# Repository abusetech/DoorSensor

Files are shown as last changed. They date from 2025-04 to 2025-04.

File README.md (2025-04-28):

# DoorSensor

This is a wireless sensor that uses an accelerometer and an NRF24l01+ wireless transceiver to monitor the state of a door thumbturn (The small knob that moves the deadbolt). The sensor physically attaches to the deadbolt and uses the accelerometer to deterimine its orientation and therefore the state of the deadbolt. This allows the device to be attached to the door without modifying the entry or causing damage. This is important in scenarios such as apartment rentals as lease agreements typically do not allow tenants to modify or replace the door lock.

This sensor is battery operated and designed to have very low power comsumption in order to allow the batteries to last a long time.

### Project contents

* Circuit schematic (board design coming soon!)
* Firmware sources, including some novel abstractions for the accelerometer and radio
* Arduino code to receive data from the remote sensor (coming soon)
* Testing tools for various parts of the project

### Firmware features

* A tiny, highly optimized software TWI (I2C compatible) implementation
* Firmware code optimized for ultra low power consumption battery powered operation

### Parts

* ATTINY44/84
* ADXL345
* NRF24L01(+) module
* 2x AAA battery holder

You will also need an Arduino board and a second NRF24L01+ to build the receiver.

### Project Plan

The Arduino will run firmware that allows it to connect to HomeAssistant. It acts as a bridge between the HomeAssistant and the wireless sensor.

### Building

Make a build directory:

`$ mkdir build`

Run `make`

`$ make all`

### Debugging

This project can be run in [simavr](https://github.com/buserror/simavr). To do so, build the binaries and then execute the ELF inside simavr:

`$ simavr -g build/attiny44.elf`

Then connect to simavr using gdb:

`avr-gdb -ex "symbol-file build/attiny44.elf" -ex "target remote localhost:1234"`

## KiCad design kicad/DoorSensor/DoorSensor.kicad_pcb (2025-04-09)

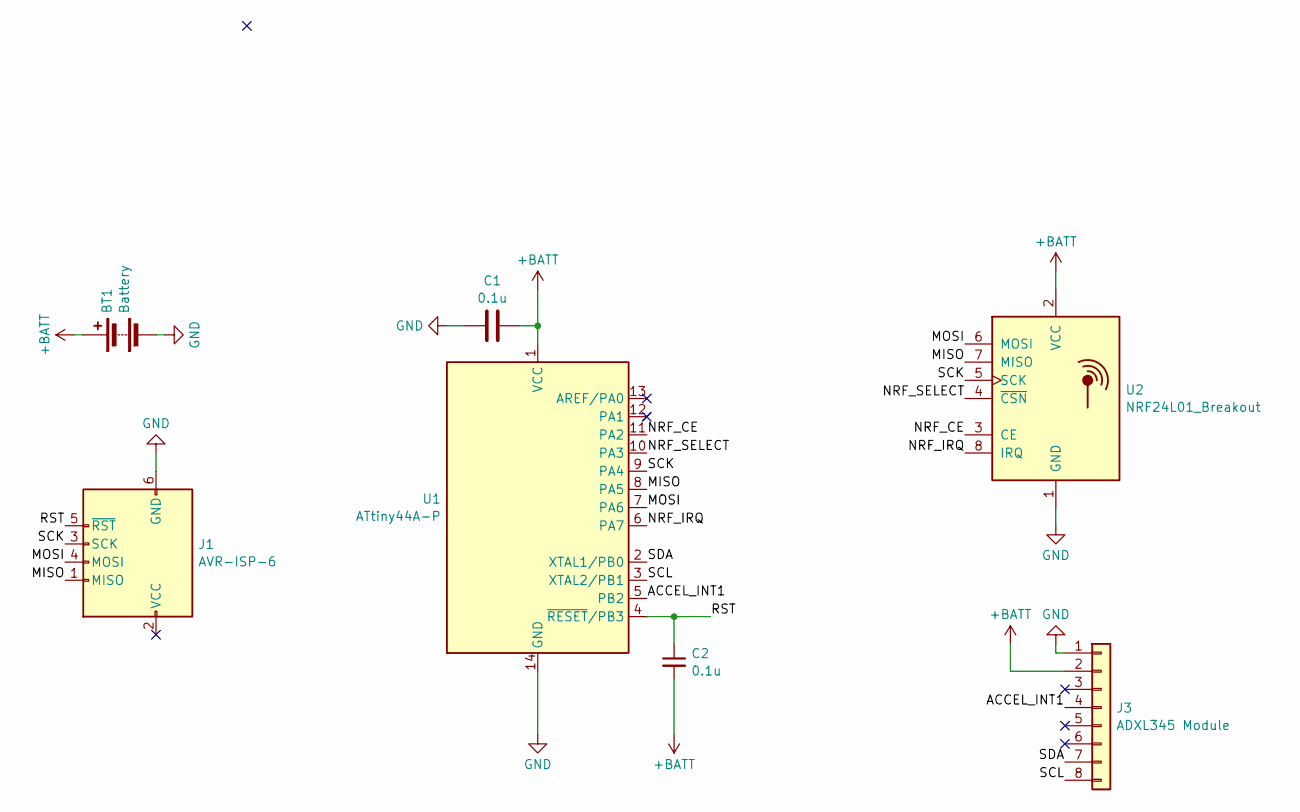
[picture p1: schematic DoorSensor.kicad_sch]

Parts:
BT1: Battery; TerminalBlock_4Ucon_1x02_P3.50mm_Horizontal
C1, C2: 0.1u; C_Disc_D4.3mm_W1.9mm_P5.00mm
J1: AVR-ISP-6; IDC-Header_2x03_P2.54mm_Vertical
J3: ADXL345 Module; PinHeader_1x08_P2.54mm_Vertical
U1: ATtiny44A-P; DIP-14_W7.62mm
U2: NRF24L01_Breakout; nRF24L01_Breakout

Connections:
+BATT: BT1.1 (+), C1.2, C2.2, J3.2, U1.1 (VCC), U2.2 (VCC)
/ACCEL_INT1: J3.4, U1.5 (PB2)
/MISO: J1.1 (MISO), U1.8 (PA5), U2.7 (MISO)
/MOSI: J1.4 (MOSI), U1.7 (PA6), U2.6 (MOSI)
/NRF_CE: U1.11 (PA2), U2.3 (CE)
/NRF_IRQ: U1.6 (PA7), U2.8 (IRQ)
/NRF_SELECT: U1.10 (PA3), U2.4 (~CSN)
/RST: C2.1, J1.5 (~RST), U1.4 (~RESET/PB3)
/SCK: J1.3 (SCK), U1.9 (PA4), U2.5 (SCK)
/SCL: J3.8, U1.3 (XTAL2/PB1)
/SDA: J3.7, U1.2 (XTAL1/PB0)
GND: BT1.2 (-), C1.1, J1.6 (GND), J3.1, U1.14 (GND), U2.1 (GND)

Board: 2 copper layers, 7 parts (1 on the bottom side), 12 nets, no tracks yet.

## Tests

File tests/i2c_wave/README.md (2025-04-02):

## I2C Wave

This is a tool for verification of the software I2C code. It utilizes a modified common.h header to inject some code into the software i2c library (softi2c.h). It is compiled using the system (as in the native one running on the development machine) C++ compiler. The customized header defines functions and variables to mock or emulate the functionality of the microcontroller. The test produces a CSV file that is read into a MATLAP / Octave sctipt that is then executed with Octave to produce a graph of the pin states.

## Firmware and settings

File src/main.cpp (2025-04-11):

#include <stdint.h>
#include <avr/io.h>
#include <avr/interrupt.h>
#include <avr/sleep.h>
#include <avr/wdt.h>
//Common.h defines F_CPU, so it must be included before delay.h
#include "common.h"
#include <util/delay.h>
#include "spi.h"
#include "softi2c.h"
#include "nrf24.h"
#include "adxl345.h"
#include "battery.h"

#define NRF_SPI_CS_PORT PORTA
#define NRF_SPI_CE_PORT PORTA
#define NRF_SPI_CS PA1
#define NRF_SPI_CE PA3
//Resolution of STATUS_TX_PERIOD is the same as the WDT timeout setting.
#define STATUS_TX_PERIOD 30

//f = 2400 + RF_CH MHz
#define RF_CHAN (25)
const uint8_t DEST_ADDRESS[5] = {0x7E, 0x7E, 0x7E, 0x7E, 0x7E};

int main (void);
void txStatus(ADXL345&);

volatile uint16_t wdt_timer = 0;
SPI nrf_spi(&NRF_SPI_CS_PORT, NRF_SPI_CS);
SoftI2C i2c;
NRF24 nrf(nrf_spi, &NRF_SPI_CE_PORT, NRF_SPI_CE);
ADXL345 accel(i2c);

//On AVR platforms, this packet will be little-endian 2's complement format
typedef struct __attribute__((packed)) status_packet {
    uint8_t sensorClass;
    uint8_t sensorID;
    uint8_t locked;
    uint16_t battery_mv;
} status_packet_t;

int main (void){
    nrf_spi.init();
    i2c.init();
    //Disable WDT, it may still be enabled after reset
    wdt_disable();
    //Wait ~100ms for periphrials to settle
    _delay_ms(100);
    //Bypass the FIFO, old values overwritten as they come in. 
    accel.fifoCtl(ADXL_FIFO_MODE_BYPASS, 0, 0);
    //Select the measurement rate. 0b0011 = 0.78Hz, 23uA consumption.
    //TODO: Power consumption could be further reduced to ~0.1uA by using standby mode (clearing the measure bit).
    accel.bwRate(0, 0b0011);
    //Enable measurement mode.
    accel.powerCtl(ADXL_POWER_MEASURE, 0);
    //Configure the NRF24L01+ module
    nrf.setDestAddress(DEST_ADDRESS, sizeof(DEST_ADDRESS));
    nrf.setChannel(RF_CHAN);
    //Enable interrupts
    sei();
    //Configure WDT. We need this to bring the chip out of standby.
    wdt_enable(WDTO_8S);
    //WDT triggers an interrupt.
    WDTCSR |= (1 << WDIE);
    //Set the sleep mode
    set_sleep_mode(SLEEP_MODE_STANDBY);
    
    
    while(true){
        //Sleep. Zzzzz.
        sleep_enable();
        sleep_cpu();
        //Clear SE bit
        sleep_disable();
        if (wdt_timer >= STATUS_TX_PERIOD){
            wdt_timer = 0;
            BatteryStatus::init();
            nrf_spi.init(); //USI needs to be re initialized after waking from sleep
            txStatus(accel);
            BatteryStatus::shutdown();
        }
    }
}

void txStatus(ADXL345& accel){
    status_packet_t pkt;
    pkt.sensorClass = 15;
    pkt.sensorID = 103;
    //Read accelerometer status
    adxl_data_t accelData = accel.readFifo();
    //in +/- 2g mode, the axis scaling factor is 4mg / LSB.
    //therefore, we expect a read of ~250 for any axis pointed straight up.
    //if we take any angle > 30 degrees from vertical to be 'open'
    //then 250 * sqrt(3)/2 = 250 * 0.866 = 216.5
    pkt.locked = 1;
    if (accelData.datay < 216){
        pkt.locked = 0;
    }
    pkt.battery_mv = BatteryStatus::measure_mv();
    //transmit
    nrf.transmit(&pkt, sizeof(pkt));
}

ISR(WDT_vect){
    //Clear SE bit
    sleep_disable();
    wdt_timer += 8;
    //Next WDT triggers an interrupt.
    WDTCSR |= (1 << WDIE);
}

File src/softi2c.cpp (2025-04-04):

#include "softi2c.h"

/*
*
* Pins and port must be defined before this file is included.
* #define I2C_PORT PORTB
* #define I2C_PIN PINB
* #define I2C_DDR DDRB
* #define I2C_SDA PB0
* #define I2C_SCL PB1
* #define I2C_CLOCK_PERIOD 1000
*
*/

//The following one liners *SHOULD* compile to sbi or cbi instructions.
//No need for inline assembly here.

static inline void _I2C_SDA_LOW(){
    I2C_DDR |= (1 << I2C_SDA);
}

static inline void _I2C_SDA_HIGH(){
    I2C_DDR &= ~(1 << I2C_SDA);
};

static inline void _I2C_SCL_LOW(){
    I2C_DDR |= (1 << I2C_SCL);
}

static inline void _I2C_SCL_HIGH(){
    I2C_DDR &= ~(1 << I2C_SCL);
};

//returns 1 or 0 depending on the state of the SDA pin
static inline uint8_t _I2C_READ_SDA(){
    return (I2C_PIN & (1 << I2C_SDA)) >> I2C_SDA;
}

//PUMP_BIT puts a bit onto the bus, starting 1/4 cycle before the rising edge of the clock
//and waiting 1/4 cycle of space (clock low) time.
static void _I2C_PUMP_BIT(uint8_t b){
    _I2C_SCL_LOW();
    if (b>0){
        _I2C_SDA_HIGH();
    }else{
        _I2C_SDA_LOW();
    }
    _delay_us(I2C_CLOCK_PERIOD>>2);
    _I2C_SCL_HIGH();
    _delay_us(I2C_CLOCK_PERIOD>>1);
    _I2C_SCL_LOW();
    _delay_us(I2C_CLOCK_PERIOD>>2);
}

//Assumes SCA/SCL HIGH
static void _I2C_START(){
    _I2C_SDA_LOW();
    _delay_us(I2C_CLOCK_PERIOD>>2);
    _I2C_SCL_LOW();
    _delay_us(I2C_CLOCK_PERIOD>>2);
}

static void _I2C_STOP(){
    _I2C_SDA_LOW();
    _delay_us(I2C_CLOCK_PERIOD>>2);
    _I2C_SCL_HIGH();
    //Wait and release SDA
    _delay_us(I2C_CLOCK_PERIOD>>2);
    _I2C_SDA_HIGH();
    _delay_us(I2C_CLOCK_PERIOD>>2);
}

//Wait for ACK after last bit transmitted.
//returns at the END of the clock pulse
static uint8_t _I2C_WAIT_ACK(){
    uint8_t sda;
    _I2C_SDA_HIGH();
    _delay_us(I2C_CLOCK_PERIOD>>2);
    _I2C_SCL_HIGH();
    _delay_us(I2C_CLOCK_PERIOD>>2);
    sda = _I2C_READ_SDA();
    _delay_us(I2C_CLOCK_PERIOD>>2);
    return sda;
}

uint8_t SoftI2C::writeBytes(uint8_t address, uint8_t bytes[], uint8_t count){
    uint8_t ack = 0;
    _I2C_START();
    //Last bit 0 indicates a write
    address = (address << 1);
    for (uint8_t i = 0; i < 8; i++){
        _I2C_PUMP_BIT((address << i) & 0x80);
    }
    //Wait for ACK
    ack = _I2C_WAIT_ACK();
    if(ack){
        //NACK. give up.
        return 1;
    }
    //Wait for the middle of the next space time.
    _I2C_SCL_LOW();
    _delay_us(I2C_CLOCK_PERIOD>>2);
    //Now we can write out the data. Most significant byte first.
    for (uint8_t byte_counter = 0; byte_counter < count; byte_counter++){
        for (uint8_t i = 0; i < 8; i++){
            _I2C_PUMP_BIT((bytes[byte_counter] << i) & 0x80);
        }
        //wait for ack
        ack = _I2C_WAIT_ACK();
        if(ack){
            //NACK. give up.
            return 1;
        }

        //Wait for the middle of the next space time.
        _I2C_SCL_LOW();
        _delay_us(I2C_CLOCK_PERIOD>>2);
            
    }

    //STOP condition. SCL should already be LOW at this point, but we will assert it anyways.
    _I2C_STOP();
    return 0;
}


uint8_t SoftI2C::readBytes(uint8_t address, uint8_t buffer[], uint8_t count){
    uint8_t ack = 0;
    uint8_t data = 0;
    _I2C_START();
    //Last bit 1 indicates a read
    address = (address << 1) | 1;
    for (uint8_t i = 0; i < 8; i++){
        _I2C_PUMP_BIT((address << i) & 0x80);
    }
    //Wait for ACK
    ack = _I2C_WAIT_ACK();
    if(ack){
        //NACK. give up.
        return 1;
    }
    //Wait for the middle of the next space time.
    _I2C_SCL_LOW();
    _delay_us(I2C_CLOCK_PERIOD>>2);
    //Pump in the data. MSB first.
    for (uint8_t byte_count = 0; byte_count < count; byte_count++){
        data = 0;
        for (uint8_t i = 0; i < 8; i++){
            _delay_us(I2C_CLOCK_PERIOD>>2);
            _I2C_SCL_HIGH();
            _delay_us(I2C_CLOCK_PERIOD>>2);
            data = (data << 1) | _I2C_READ_SDA();
            _delay_us(I2C_CLOCK_PERIOD>>2);
            _I2C_SCL_LOW();
            _delay_us(I2C_CLOCK_PERIOD>>2);
        }
        buffer[byte_count] = data;

        //Send ACK / NACK
        //Check if this is the last byte (this form is used because subi/bne compiles to two instructions)
        if (byte_count != count - 1){
            //ACK. Pull SDA low and pulse the clock. Return mid cycle.
            _I2C_SDA_LOW();
            _delay_us(I2C_CLOCK_PERIOD>>2);
            _I2C_SCL_HIGH();
            _delay_us(I2C_CLOCK_PERIOD>>1);
            _I2C_SCL_LOW();
            _delay_us(I2C_CLOCK_PERIOD>>2);
            _I2C_SDA_HIGH();
        }else{
            //NACK.
            _I2C_SDA_HIGH();
            _delay_us(I2C_CLOCK_PERIOD>>2);
            _I2C_SCL_HIGH();
            _delay_us(I2C_CLOCK_PERIOD>>1);
            _I2C_SCL_LOW();
            _delay_us(I2C_CLOCK_PERIOD>>2);
        }
    }
    //We are now done, so we can send a stop condition.
    //SCL is low at this point. Wait the remaining 1/4 period and then release SCL
     _I2C_STOP();
    return 0;
}

void SoftI2C::init(){
    //Both pins set to 0 (low, pull up disabled)
    I2C_PORT &= ~(1 << I2C_SDA);
    I2C_PORT &= ~(1 << I2C_SCL);
    _I2C_SDA_HIGH();
    _I2C_SCL_HIGH();
}

void SoftI2C::dummyTest(){
    uint8_t testBytes[] = {0x1f, 0x55, 0x01};
    init();
    _delay_us(500);
    writeBytes(0x1, testBytes, sizeof(testBytes));
    //readBytes(0x1, inBytes, sizeof(inBytes));
}

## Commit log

2025-03-17 Tests; Software I2C; ADXL345
    [DoorSensor.kicad_pcb, DoorSensor.kicad_sch]
2025-04-02 Fixed memory allocated to _pi in i2cwave test not zeroed; added README for test
    [adxl345.cpp, common.cpp, common.h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]
2025-04-03 read accelerometer value
2025-04-04 simavr support; initial board layout
    [DoorSensor.kicad_pcb, DoorSensor.kicad_sch]
2025-04-09 Fixed WDT causing resets instead of triggering an interrupt
    [DoorSensor.kicad_pcb]
2025-04-11 Added battery voltage measurement code
